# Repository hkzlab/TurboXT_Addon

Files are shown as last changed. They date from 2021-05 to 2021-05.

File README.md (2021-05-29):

# Turbo / Reset addon board for the IBM XT (5160)

## Introduction

This board is originally based on schematics I found floating around on VCFED, and adds the following to an IBM XT:

- Switchable clock between **standard** (4.77Mhz) and **turbo** (8Mhz if the oscillator installed on the board is 24Mhz)
- Auto disable of turbo-mode during DMA
- Reset button header

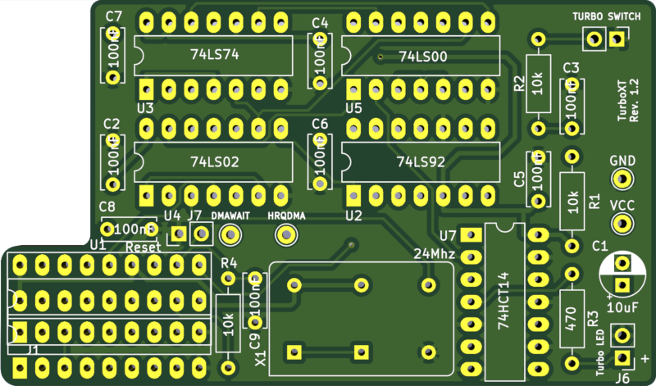
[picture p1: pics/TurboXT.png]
Rev. 1.2 PCB


### Disclaimer

I take NO responsibility for what happens if you decide to build and use this card. Your computer might crash, catch fire or be destroyed in other nasty ways.
Also, as this card is mostly based on the work of others, You're encourauged to take what you deem fit from this, and use it in your projects!

## Installation

The board is installed on the 8284 socket (near the 8088 processor) via turned pin headers, and the 8284 is placed on a socket on top of the board.
Usually, an additional socket is added to the bottom headers to gain some vertical spacing, as part of the board sits above 8088 and 8087 sockets.

The TurboXT then has 4 additional labeled connections to make on the motherboard via wire.

### DMA

These connections are required to automatically disable turbo during DMA:

- HRQDMA from pin 10 of the 8237 DMA controller (U28) or pin 5 of U57 (74LS20)
- DMAWAIT from pin 7 of a 74LS175 flipflop (U88)

Note that these two connections actually end up feeding into the same NAND gate, you can mix them up and no issue will arise.

### Power

These are optional but highly recommended to provide an additional source of power beside the 8284 socket:

- VCC: Connect to a +5V spot on the board
- GND: Connect to a GND spot on the board

There are many connection points you can use (VCC/GND legs of another IC for example), but along the side of the XT power connector
there are two empty resistor footprints on my board that were perfect for the connection.

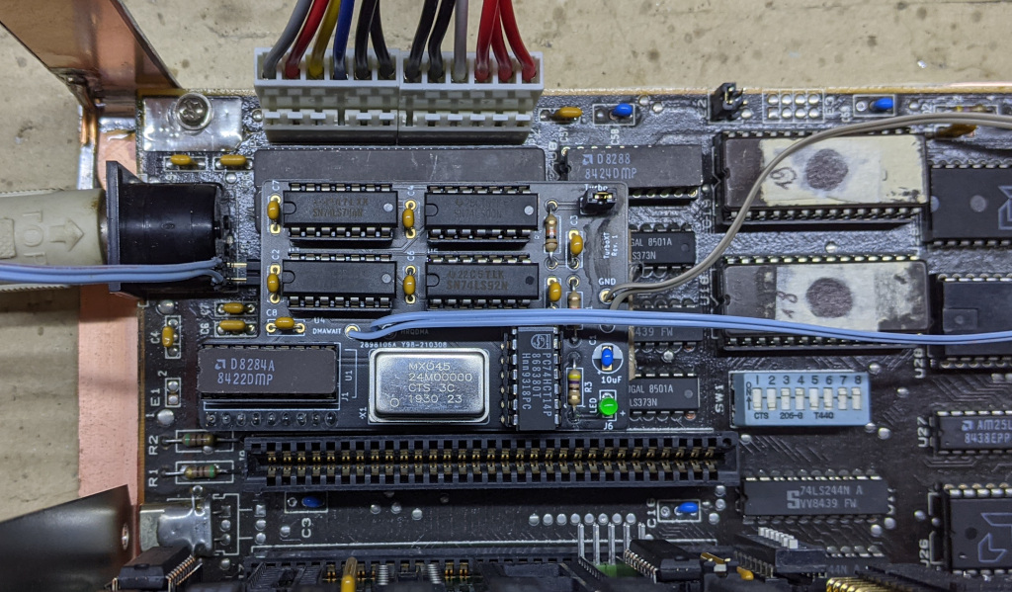
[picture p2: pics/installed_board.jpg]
Installed board


**Check continuity with a multimeter!!!**

# Known issues and caveats 

- The original 8088 is rated 5Mhz. Replace it with at least an 8Mhz rated variant.
- The board sits on top of (but should not make contact with) the 8088 and 8087. These can get hot, add a fan or something to keep them cooler.
- Some CMOS variants of the 8284 do not drive the OSC signal when the F/C pin is high. This is required for this board to work. I tested mine with the original Intel 8284.
- The components on top of the board could cause some clearance issues with cards installed in slot 8. Some redesigning is required to address this.
- You can try other oscillators in place of the 24Mhz one. Remember that the resulting frequency will be divided by 3.

## Bill of Materials

- C1:	10uF/25v electrolitic cap
- C2-9: 8x 100nF ceramic caps
- R1, R2, R4: 3x 10k resistors
- R3: 470ohm resistors
- U2: 74LS92
- U3: 74LS74
- U4: 74LS02
- U5: 74LS00
- U7: 74HCT14
- X1: 24Mhz oscillator (The board divides this frequency by 3)
- 18pin socket for 8284
- 18pin turned header strip
- 18pin socket as a spacer between motherboard and addon
- Snapped pin headers for connectors on the board

# Credits

Original schematics from [this](www.vcfed.org/forum/showthread.php?70923-IBM-5160-overclock-Sergey%92s-way) thread on VCFED.

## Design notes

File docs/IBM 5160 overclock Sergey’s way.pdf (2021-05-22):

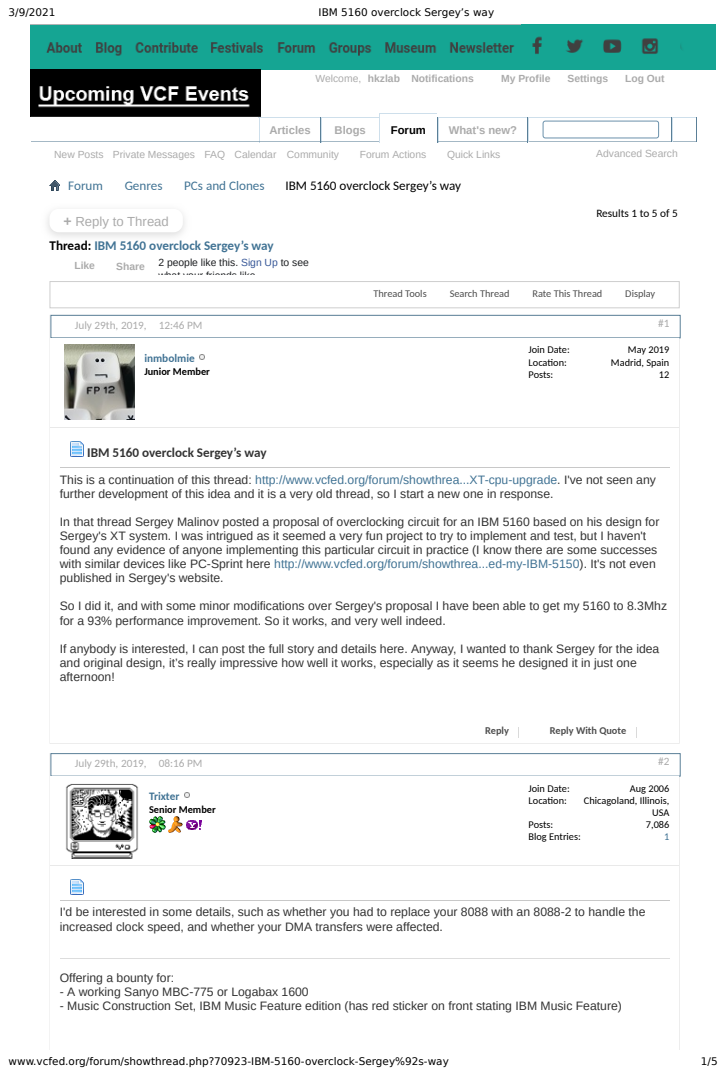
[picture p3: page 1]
IBM 5160 overclock Sergey’s way; www.vcfed.org/forum/showthread.php?70923-IBM-5160-overclock-Sergey%92s-way; Forum; Genres; PCs and Clones; Welcome, hkzlab Notifications; My Profile; Settings; Log Out; Articles; Blogs; What's new?; New Posts Private Messages FAQ Calendar Community; Forum Actions; Quick Links; Advanced Search; + Reply to Thread; Results 1 to 5 of 5; Like; Share; Thread Tools; Search Thread; Rate This Thread; Display; July 29th, 2019, 12:46 PM; Join Date: Locaon: Posts: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

Thread: IBM 5160 overclock Sergey’s way (http://www.vcfed.org/forum/showthread.php?70923-IBM-5160-overclock-Sergey%92s-way)

2 people like this. Sign Up (https://www.facebook.com/ad_campaign/landing.php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) to see
what your friends like

IBM 5160 overclock Sergey’s way
This is a continuation of this thread: http://www.vcfed.org/forum/showthrea...XT-cpu-upgrade. (http://www.vcfed.org/forum/showthread.php?41940-IBM-XT-cpu-upgrade) I've not seen any
further development of this idea and it is a very old thread, so I start a new one in response.

In that thread Sergey Malinov posted a proposal of overclocking circuit for an IBM 5160 based on his design for
Sergey's XT system. I was intrigued as it seemed a very fun project to try to implement and test, but I haven't
found any evidence of anyone implementing this particular circuit in practice (I know there are some successes
with similar devices like PC-Sprint here http://www.vcfed.org/forum/showthrea...ed-my-IBM-5150). (http://www.vcfed.org/forum/showthread.php?60803-I-overclocked-my-IBM-5150) It's not even
published in Sergey's website.

So I did it, and with some minor modifications over Sergey's proposal I have been able to get my 5160 to 8.3Mhz
for a 93% performance improvement. So it works, and very well indeed.

If anybody is interested, I can post the full story and details here. Anyway, I wanted to thank Sergey for the idea
and original design, it’s really impressive how well it works, especially as it seems he designed it in just one
afternoon!

I'd be interested in some details, such as whether you had to replace your 8088 with an 8088-2 to handle the
increased clock speed, and whether your DMA transfers were affected.

Offering a bounty for:
- A working Sanyo MBC-775 or Logabax 1600
- Music Construction Set, IBM Music Feature edition (has red sticker on front stating IBM Music Feature)

www.vcfed.org/forum/showthread.php?70923-IBM-5160-overclock-Sergey%92s-way | 2/5
Reply (http://www.vcfed.org/forum/newreply.php?do=newreply&p=580699&noquote=1) | Reply With Quote (http://www.vcfed.org/forum/newreply.php?do=newreply&p=580699)

July 29th, 2019, 09:28 PM

| Join Date: Locaon: Posts:

May 2019
| Madrid, Spain
12

Yes, I replaced the original 8088 (mine was an IBM part number) but with an 8Mhz NEC V20. The reason was not the overclock itself but that I wanted to attach a Sound Blaster 16 to my system and to run its configuration program the 80186 instruction set is required. As a side effect you get some small performance improvement. Anyway it was cheaper and more convenient to get it locally than an 8 or 10Mhz 8088.

Regarding the DMA transfers, they were affected but much less than expected. Up to 18-20Mhz oscillator speeds (6-6.7Mhz) they wasn't affected at all. To get full speed you definitely need to attach the DMA signals to the circuit. Over 20Mhz I got hard disk access errors. Over 22Mhz the system won't even get to POST without the signals attached.

Take into account that I have a late revision mainboard, I suppose that the achievable speeds can change a lot between different revisions and components.

#3 (http://www.vcfed.org/forum/showthread.php?70923-IBM-5160-overclock-Sergey%92s-way&p=580707)

Junior Member

inmbolmie (http://www.vcfed.org/forum/member.php?50099-inmbolmie)

Originally Posted by Trixter

I'd be interested in some details, such as whether you had to replace your 8088 with an 8088-2 to handle the increased clock speed, and whether your DMA transfers were affected.

Reply (http://www.vcfed.org/forum/newreply.php?do=newreply&p=580707&noquote=1) | Reply With Quote (http://www.vcfed.org/forum/newreply.php?do=newreply&p=580707)

August 1st, 2019, 11:58 PM

| Join Date: Locaon: Posts:

May 2019
| Madrid, Spain
12

I'll give the full details here. If you try, be aware that it can void your warranty...

So first, this is the original schematic:

http://www.vcfed.org/forum/attachmen...4&d=1395123082 (http://www.vcfed.org/forum/attachment.php?attachmentid=17804&d=1395123082)

And this is my modified schematic.

turbo8088 v2.pdf (http://www.vcfed.org/forum/attachment.php?attachmentid=54987&d=1564694535)

Things that I’ve changed from Sergey’s schematic:

As Sergey says in the original thread, the wiring in the 74LS92 counter used to generate PCLK is incorrect. I’ve changed it to generate a clock of 1/3 OSC frequency. Also I see no reason to wire this counter to the reset circuit so I removed that connections.
There is no separate reset circuit, everything is connected to the system RESET lines. The reason is that I found that keyboard initialization is picky about reset timing, and using the separate circuit often ended in 301 POST errors and a non-functional keyboard. The original reset signal is related to a signal that comes from the power supply that tells the system that its power output is stable enough to run (PWR_GOOD).
I’ve added a debouncing circuit to the TURBO input signal. This is based on a 74LS14 (Schmitt trigger inverter). The signal comes from a mechanical switch, so it is much cleaner to pass it through the debouncer.

#4 (http://www.vcfed.org/forum/showthread.php?70923-IBM-5160-overclock-Sergey%92s-way&p=581133)

Junior Member

inmbolmie (http://www.vcfed.org/forum/member.php?50099-inmbolmie)

www.vcfed.org/forum/showthread.php?70923-IBM-5160-overclock-Sergey%92s-way | 3/5

Everything else is as specified in Sergey’s design.

For the installation the difficult part is interfacing this circuit with the 5160 mainboard. The circuit replaces the 8284 clock generator that is just next to the main 8088 CPU. You can be lucky and get a mainboard that has its 8284 socketed, or you can be unlucky (like me) and have the IC directly soldered to the board. If socketed, you simply unplug the 8284 and replace it with a custom built cable that goes pin-to-pin to the overclocking circuit. If soldered, you have to disassemble the entire system to remove the mainboard, unsolder the 8284 and solder a proper DIP18 socket in its place. This can be a real pain if you don’t have the proper equipment.

Regardless of needing or not the 8284 desoldering operation, if you want to go high in overclocking you will need at least to remove the floppy drive and hard disk to get access to the needed DMA signals (HRQDMA and DMAWAIT) that will disable TURBO operation when DMA activity is detected. If you don’t, you will first have unreliable DMA operation (hard disk errors) and if you go high enough the system will not even get to POST. As an example in my case hard disk operation becomes unreliable with an oscillator over 20MHZ and won’t post over 22MHz. Up to 20Mhz I had no DMA issues even without the signals connected, but other systems could be less permissive.

This is the location of those signals in my mainboard. I got the locations from the IBM 5160 technical reference guide:

HRQDMA from pin 10 of the 8237 DMA controller (U28 )
DMAWAIT from pin 7 of a 74LS175 flipflop (U88 ). It seems that can also be obtained inverting pin
4 from the 8284 as it should be connected to pin 6 of U88, but pin 7 gives it not inverted.

I built a custom pint-to-pin DIP18 to DIP18 cable using an old IDE ribbon cable, two DIP18 ribbon connectors and two DIP18 turned sockets. It takes 5 minutes to make it. The cable length is approx. 20 cm.

My ribbon connectors are DIP20 but only because that was what I had readily available, they work well with a DIP18 turned socket.

The first prototype I made was using a breadboard. This version has a 20Mhz clock generator and lacks the antibouncing circuit.

Then for the final circuit I used a soldered prototype board. Good enough for the moment, cheap and can be made very quickly.

www.vcfed.org/forum/showthread.php?70923-IBM-5160-overclock-Sergey%92s-way | 4/5

Finally a toggle switch for better retro looking to enable and disable turbo mode, installed drilling an empty ISA bracket

Some details and “lessons learnt” through the process:

Used an 8Mhz rated V20 processor in place of the original 8088. V20 is not required, but gives some extra performance and enables use of applications that require the 80186 instruction set. Removed entirely my 8087 coprocessor as it gave me many stability issues even at stock speed. Didn’t even bother to get a higher rated part, as I have no particular interest in running Lotus 1-2-3 overclocked or something.
With the original 8284 clock generator I couldn’t get over 20Mhz. I replaced it for an AMD part I got from Ebay. With this I can go up to 25Mhz oscillator speed. My local electronics shop sold me as a replacement a NEC 71084 (supposedly pin compatible with 8284), but it doesn’t work with this design because it doesn’t drive the OSC output when F/C signal is high. The real 8284 drives OSC always from the crystal input frequency regardless of the F/C signal state.
I have a late revision 64-256Kb board and a 384KB ISA expansion card. Mostly 150ns 4164 ram modules. No particular issues with onboard RAM to get to 25Mhz. The expansion card is a different history, as for going over 24Mhz I had to replace some 150ns modules with 120 ns modules. The replaced 150ns modules just work fine if I place them in the mainboard banks, but fail miserably if placed in the expansion card. I imagine that expansion card memory has some more strict timing issues that mainboard memory.
Over 24Mhz I have some memory corruption and graphics glitches in my EGA card (paradise PEGA2A) unless I place a cooling fan in front of it. It’s not strictly an overheating problem because if I switch off overclocking it instantly works fine. No problem at 24Mhz though. I haven’t tried using a CGA card (can get a look if someone is interested).

As said, the faster I can get is 25Mhz OSC, equivalent to 8.33Mhz CPU clock speed. Around that speed everything seems to begin falling apart. Checkit reports CPU speed as 7.91Mhz because I imagine there is some background DMA activity that reduces slightly the effective clock speed. No problem at that speed to pass any memory or integrity test, although the graphics card needs some extra cooling for glitchless operation.

Reply (http://www.vcfed.org/forum/newreply.php?do=newreply&p=581133&noquote=1) | Reply With Quote (http://www.vcfed.org/forum/newreply.php?do=newreply&p=581133)

October 25th, 2019, 01:37 AM

| Join Date: Locaon: Posts:

Dec 2009
Canada
287

#5 (http://www.vcfed.org/forum/showthread.php?70923-IBM-5160-overclock-Sergey%92s-way&p=591714)

Senior Member

Twospruces (http://www.vcfed.org/forum/member.php?10037-Twospruces)

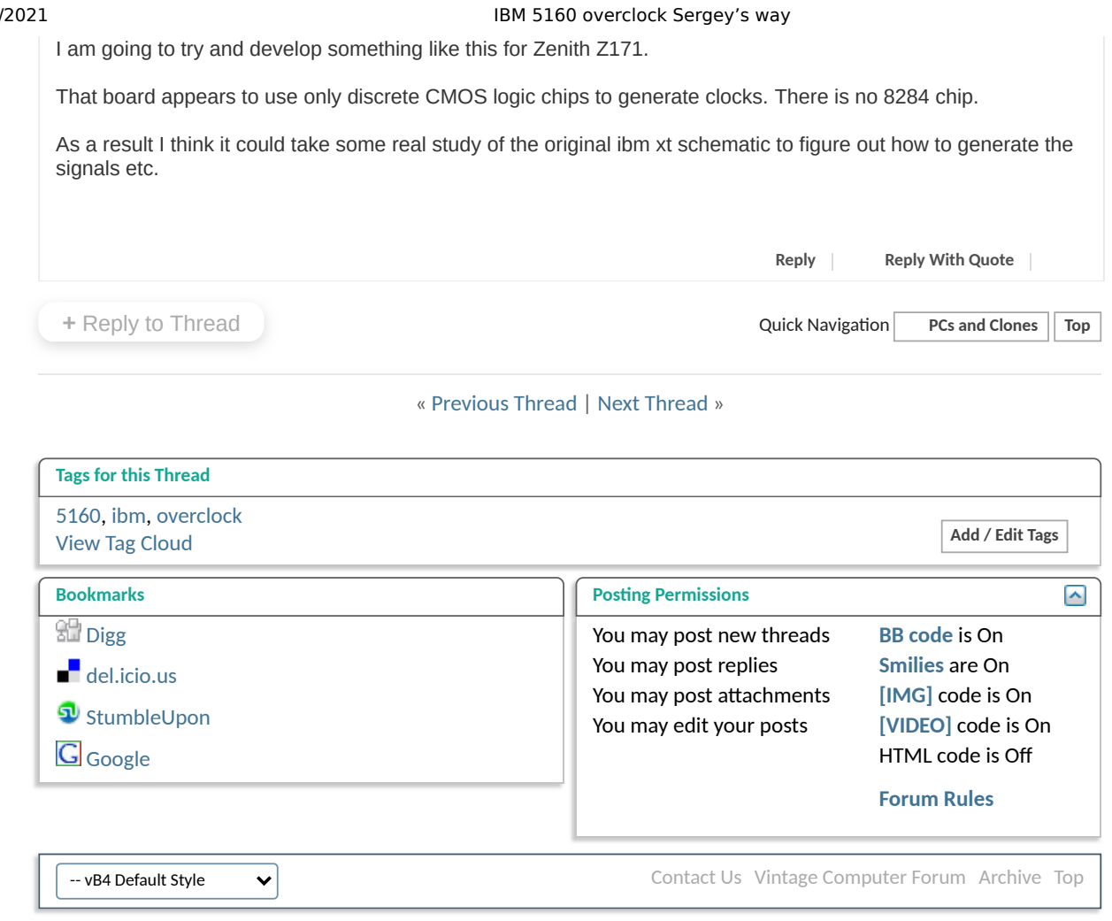
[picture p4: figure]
-- vB4 Default Style; « Previous Thread | Next Thread »; signals etc.; Reply; Reply With Quote; + Reply to Thread; Quick Navigaon; PCs and Clones; Top; Tags for this Thread; 5160, ibm, overclock; View Tag Cloud; Add / Edit Tags; Digg; del.icio.us; StumbleUpon; Google; Bookmarks; You may post new threads You may post replies You may post aachments You may edit your posts; Posng Permissions; BB code is On Smilies are On [IMG] code is On [VIDEO] code is On HTML code is Off; Forum Rules

www.vcfed.org/forum/showthread.php?70923-IBM-5160-overclock-Sergey%92s-way | 5/5

Contact Us (http://www.vcfed.org/forum/sendmessage.php) Vintage Computer Forum (http://www.vcfed.org/) Archive (http://www.vcfed.org/forum/archive/index.php) Top (http://www.vcfed.org/forum/showthread.php?70923-IBM-5160-overclock-Sergey%92s-way#top)

All mes are GMT +1. The me now is 11:10 AM.

Powered by vBullen® (https://www.vbulletin.com/) Version 4.2.5
Copyright © 2021 vBullen Soluons Inc. All rights reserved.

© 2002-2019 Vintage Computer Federaon, all rights reserved

I am going to try and develop something like this for Zenith Z171.

That board appears to use only discrete CMOS logic chips to generate clocks. There is no 8284 chip.

As a result I think it could take some real study of the original ibm xt schematic to figure out how to generate the

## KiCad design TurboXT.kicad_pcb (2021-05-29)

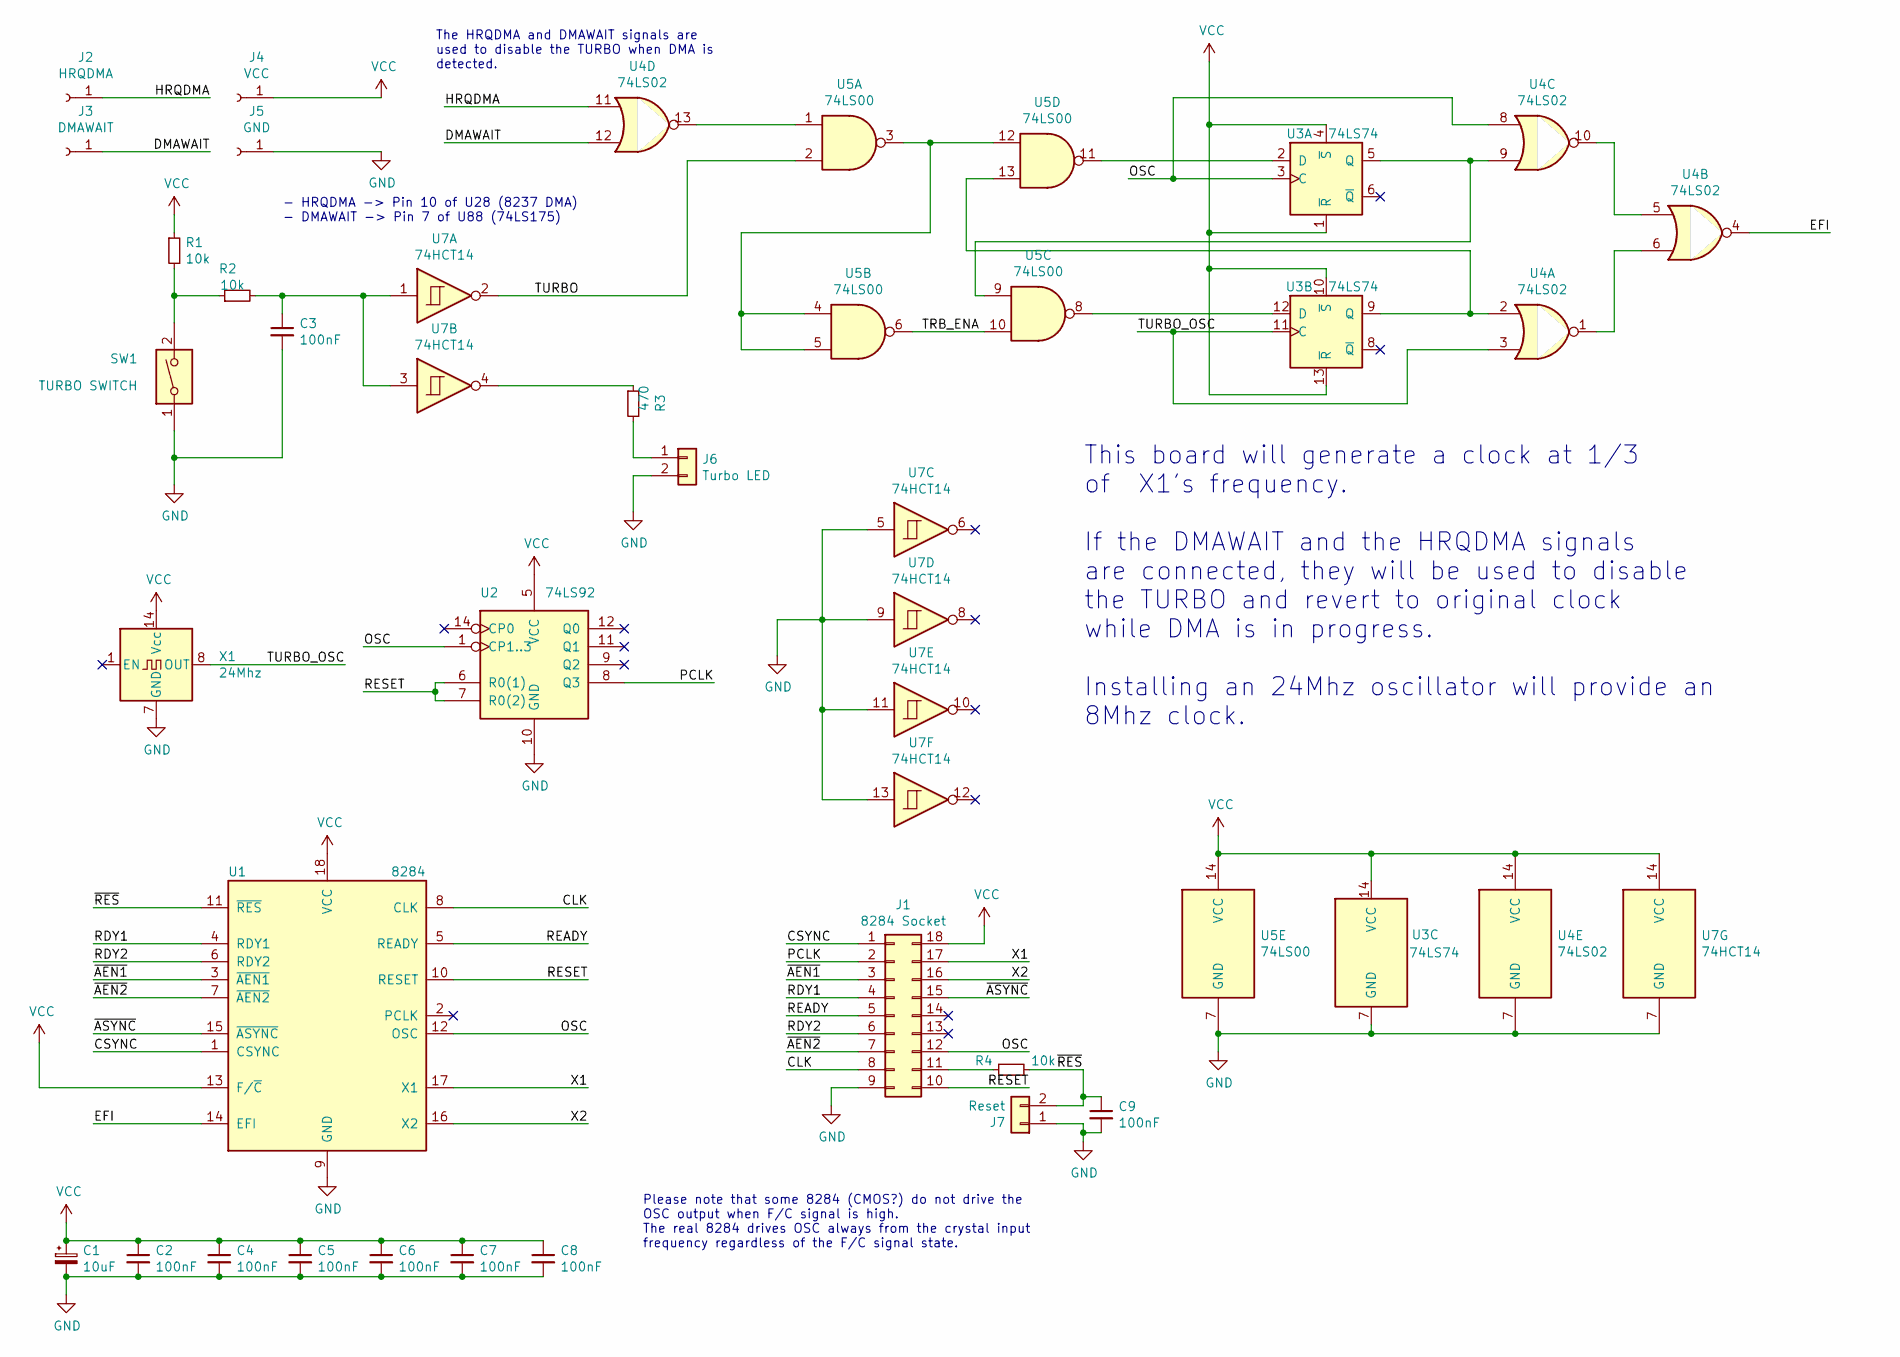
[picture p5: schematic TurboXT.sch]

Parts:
C1: 10uF; CP_Radial_D5.0mm_P2.50mm
C2, C3, C4, C5, C6, C7, C8, C9: 100nF; C_Disc_D6.0mm_W2.5mm_P5.00mm
J1: 8284 Socket; DIP-18_W7.62mm_LongPads
J2: HRQDMA; Pin_D1.0mm_L10.0mm
J3: DMAWAIT; Pin_D1.0mm_L10.0mm
J4: VCC; Pin_D1.0mm_L10.0mm
J5: GND; Pin_D1.0mm_L10.0mm
J6: Turbo LED; PinHeader_1x02_P2.54mm_Vertical
J7: Reset; PinHeader_1x02_P2.54mm_Vertical
R1, R2, R4: 10k; R_Axial_DIN0207_L6.3mm_D2.5mm_P10.16mm_Horizontal
R3: 470; R_Axial_DIN0207_L6.3mm_D2.5mm_P10.16mm_Horizontal
SW1: TURBO SWITCH; PinHeader_1x02_P2.54mm_Vertical
U1: 8284; DIP-18_W7.62mm_Socket_LongPads
U2: 74LS92; DIP-14_W7.62mm_LongPads
U3: 74LS74; DIP-14_W7.62mm_LongPads
U4: 74LS02; DIP-14_W7.62mm_LongPads
U5: 74LS00; DIP-14_W7.62mm_LongPads
U7: 74HCT14; DIP-14_W7.62mm_LongPads
X1: 24Mhz; Oscillator_DIP-14-8

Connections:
/CLK: J1.8, U1.8 (CLK)
/CSYNC: J1.1, U1.1 (CSYNC)
/DMAWAIT: J3.1, U4.12
/EFI: U1.14 (EFI), U4.4
/HRQDMA: J2.1, U4.11
/OSC: J1.12, U1.12 (OSC), U2.1 (CP1..3), U3.3 (C), U4.8
/PCLK: J1.2, U2.8 (Q3)
/RDY1: J1.4, U1.4 (RDY1)
/RDY2: J1.6, U1.6 (RDY2)
/READY: J1.5, U1.5 (READY)
/RESET: J1.10, U1.10 (RESET), U2.6 (R0(1)), U2.7 (R0(2))
/TRB_ENA: U5.6, U5.10
/TURBO: U5.2, U7.2
/TURBO_OSC: U3.11 (C), U4.3, X1.8 (OUT)
/X1: J1.17, U1.17 (X1)
/X2: J1.16, U1.16 (X2)
/~AEN1: J1.3, U1.3 (~AEN1~)
/~AEN2: J1.7, U1.7 (~AEN2~)
/~ASYNC: J1.15, U1.15 (~ASYNC~)
/~RES: C9.1, J7.2, R4.2, U1.11 (~RES~)
GND: C1.2, C2.2, C3.2, C4.2, C5.2, C6.2, C7.2, C8.2, C9.2, J1.9, J5.1, J6.2, J7.1, SW1.1, U1.9 (GND), U2.10 (GND), U3.7 (GND), U4.7 (GND), U5.7 (GND), U7.5, U7.7 (GND), U7.9, U7.11, U7.13, X1.7 (GND)
unnamed: C3.1, R2.2, U7.1, U7.3
unnamed: J1.11, R4.1
unnamed: J6.1, R3.2
unnamed: R1.2, R2.1, SW1.2
unnamed: R3.1, U7.4
unnamed: U3.2 (D), U5.11
unnamed: U3.5 (Q), U4.9, U5.9
unnamed: U3.9 (Q), U4.2, U5.13
unnamed: U3.12 (D), U5.8
unnamed: U4.1, U4.6
unnamed: U4.5, U4.10
unnamed: U4.13, U5.1
unnamed: U5.3, U5.4, U5.5, U5.12
VCC: C1.1, C2.1, C4.1, C5.1, C6.1, C7.1, C8.1, J1.18, J4.1, R1.1, U1.13 (F/~C~), U1.18 (VCC), U2.5 (VCC), U3.1 (~R), U3.4 (~S), U3.10 (~S), U3.13 (~R), U3.14 (VCC), U4.14 (VCC), U5.14 (VCC), U7.14 (VCC), X1.14 (Vcc)

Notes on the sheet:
The HRQDMA and DMAWAIT signals are used to disable the TURBO when DMA is detected.
This board will generate a clock at 1/3 of X1's frequency. If the DMAWAIT and the HRQDMA signals are connected, they will be used to disable the TURBO and revert to original clock while DMA is in progress. Installing an 24Mhz oscillator will provide an 8Mhz clock.
- HRQDMA -> Pin 10 of U28 (8237 DMA) - DMAWAIT -> Pin 7 of U88 (74LS175)
Please note that some 8284 (CMOS?) do not drive the OSC output when F/C signal is high. The real 8284 drives OSC always from the crystal input frequency regardless of the F/C signal state.

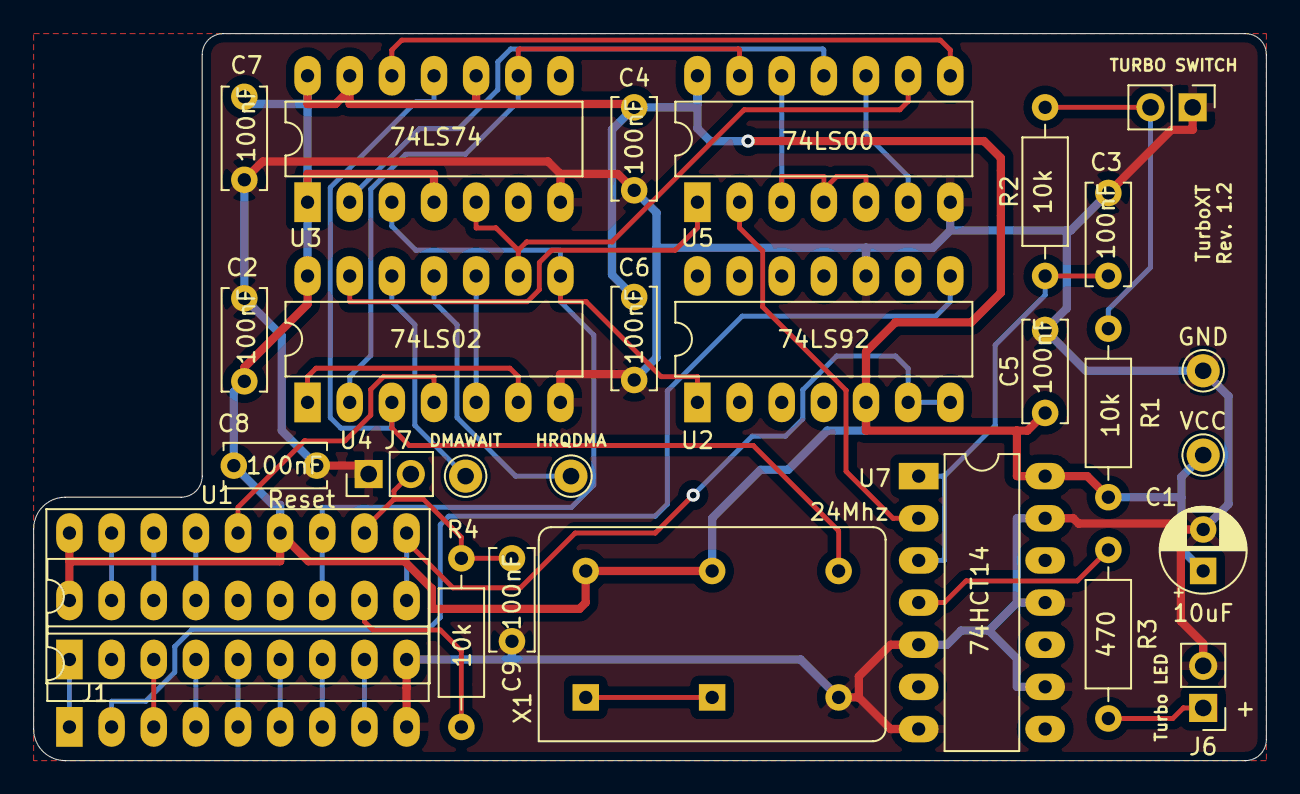
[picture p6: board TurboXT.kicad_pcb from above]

Board: 2 copper layers, 74.3 x 43.8 mm, 28 parts (0 on the bottom side), 35 nets.

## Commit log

2021-03-08 TurboXT addon schematic
    [TurboXT.kicad_pcb, TurboXT.sch]
2021-03-08 Drawn the schematic
    [TurboXT.kicad_pcb, TurboXT.sch]
2021-03-08 Gerbers + silkscreen
    [TurboXT.kicad_pcb]
2021-03-08 Change connection for led
    [TurboXT.kicad_pcb, TurboXT.sch]
2021-03-08 Fix schematics
    [TurboXT.sch]
2021-05-21 Add notes to PCB and changed silkscreen
    [TurboXT.kicad_pcb, TurboXT.sch]
2021-05-21 More notes in schematics
    [TurboXT.sch]
2021-05-22 Add original schematics
2021-05-22 Add old schematics
2021-05-22 Add notes
    [TurboXT.sch]
2021-05-28 Connect reset of 74LS92
    [TurboXT.kicad_pcb, TurboXT.sch]
2021-05-28 Change led value and silkscreen
    [TurboXT.kicad_pcb, TurboXT.sch]
2021-05-28 Updated silkscreen
    [TurboXT.kicad_pcb, TurboXT.sch]
2021-05-28 Add reset button
    [TurboXT.kicad_pcb, TurboXT.sch]
2021-05-28 Move silkscreen a bit
    [TurboXT.kicad_pcb]
2021-05-28 Add cap for deboucing
    [TurboXT.kicad_pcb, TurboXT.sch]
2021-05-29 Start writing the README
    [TurboXT.kicad_pcb]

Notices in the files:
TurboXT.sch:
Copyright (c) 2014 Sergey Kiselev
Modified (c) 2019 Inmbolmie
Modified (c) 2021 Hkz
